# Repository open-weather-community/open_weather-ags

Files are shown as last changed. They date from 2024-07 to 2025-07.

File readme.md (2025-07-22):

# Open-Weather Automated Ground Station (AGS)

An open-source hardware and software project for autonomous weather satellite reception from NOAA satellites using Automatic Picture Transmission (APT). This project enables distributed collection of weather satellite imagery for the open-weather Public Archive.

## Overview

The Open-Weather AGS is designed to be:
- **Autonomous** - Operates without manual intervention
- **Educational** - Entry point for learning about satellites, radio, and weather
- **Resilient** - Graceful handling of failures and network issues
- **Open Source** - All hardware designs, software, and documentation freely available

## Quick Start

If you have a fully assembled AGS:

1. Edit the `ow-config.json` file on the USB drive with your station details
2. Insert the USB drive into your AGS
3. Power on the device
4. The system will automatically start receiving satellite passes

To manually start the application:
```bash
npm start
```

To validate your system setup:
```bash
npm run validate
```

## Configuration

Create (or edit) a file named `ow-config.json` on your USB drive. Here's the configuration template:

```json
{
  "wifiName": "your_wifi_network",
  "wifiPassword": "your_wifi_password",
  "auth_token": "your_openweather_api_token",
  "myID": 1,
  "locLat": 52.49548,
  "locLon": 13.46843,
  "gain": 38,
  "maxDistance": 2200000,
  "daysToPropagate": 1,
  "minElevation": 30,
  "bufferMinutes": 0,
  "numberOfPassesPerDay": 1,
  "sampleRate": "48k",
  "downsample": true,
  "noaaFrequencies": {
    "NOAA 19": "137.1M",
    "NOAA 15": "137.62M"
  },
  "passesFile": "passes.json",
  "saveDir": "/media/openweather/ow",
  "logFile": "log.txt",
  "rtl_fm_path": "/usr/local/bin/rtl_fm",
  "sox_path": "/usr/bin/sox"
}
```

### Essential Configuration Parameters

The following settings are the most important to configure for your station:

- **`myID`** - Unique station identifier (provided by open-weather)
- **`locLat`** / **`locLon`** - Your station's latitude and longitude (decimal degrees)
- **`wifiName`** / **`wifiPassword`** - Your WiFi network credentials
- **`auth_token`** - Your open-weather API authentication token
- **`gain`** - RTL-SDR gain setting (adjust based on signal quality)

### Advanced Configuration

- **`maxDistance`** - Maximum satellite distance in meters to consider a viable pass
- **`daysToPropagate`** - Days in advance to calculate satellite passes
- **`minElevation`** - Minimum pass elevation in degrees (higher = better signal quality)
- **`bufferMinutes`** - Recording buffer time before/after calculated pass times
- **`numberOfPassesPerDay`** - Maximum number of recordings per day

**Note:** NOAA-18 has been removed from the default configuration as it reached end-of-life in 2024 and is no longer operational.

## System Architecture

### Core Components

- **`scheduler.js`** - Main application orchestrator and recording scheduler
- **`config.js`** - Configuration management with backup/recovery system
- **`tle.js`** - Two-Line Element data processing and satellite pass calculation
- **`recorder.js`** - Automated satellite signal recording using RTL-SDR
- **`upload.js`** - Data transmission to open-weather Public Archive
- **`network.js`** - Network connectivity management with ethernet priority
- **`lcd.js`** - LCD display interface for status and error messages
- **`logger.js`** - Centralized logging with file rotation

### File Structure

```
/home/openweather/open_weather-ags/     # Main application directory
├── scheduler.js                        # Main entry point
├── config.js                          # Configuration management
├── *.js                               # Other core modules
└── 3d/                                # 3D printing files
    ├── ready-to-print/
    └── design-and-archive/

/media/[usb-device]/                    # USB storage
├── ow-config.json                      # Station configuration
├── ow-config-backup.json              # Automatic backup
├── passes.json                         # Calculated satellite passes
├── log.txt                            # System logs
└── recordings/                         # Captured audio files
```

## Setup

Regardless of whether or not you use the automatic install vs. a manual install, some things must be prepped on the Raspberry Pi first.

### Raspberry Pi interfaces
+ Install latest [Raspberry Pi OS](https://www.raspberrypi.com/software/). At the time of writing this I am using v12 (Bookworm). It's probably best to stick to this version.
+ Use ```openweather``` for the username.
+ Enable SSH and I2C
```bash
sudo raspi-config
# then Interface, then see SSH and I2C options
```
You can test I2C with:
```bash
sudo i2cdetect -y 1
```
This will give you the address (likely 0x27) which should be used when initializing the device in the node project.

### Create an ssh key for the raspberry pi and add it to github as a deploy key

```sh
ssh-keygen
```

This will grant access to repo pushing rights, so probably not relevant to most (or any) other people.

### Software (quick way -- manual instructions below)

```sh
bash <(curl -s https://gist.githubusercontent.com/prismspecs/17b3a23be1fc6afe79f2788c9797bd21/raw/f21a18a964146081f2a6e9c3b4b80c783bbe24b7/open-weather_installer.sh)
```

```bash
git clone https://github.com/open-weather-community/open_weather-ags.git
cd open_weather-ags
chmod +x install.sh
./install.sh
npm install
```

## Manual Updates

If you need to manually update your AGS to a specific version or development branch, follow these steps:

### 1. Bypass Automatic Version Control

The AGS will automatically download the "regular" version when it boots UNLESS there is a file in your home directory named `bypass-version-check`. Create this file:

```bash
touch ~/bypass-version-check
```

This allows you to continue using the test version straight from GitHub without the system trying to correct itself. To return the AGS to normal automatic updates, simply rename or remove that file.

**Note:** The file does not have an extension (like .txt).

### 2. Remove Current AGS Directory

Remove the existing AGS installation:

```bash
rm -rf ~/open_weather-ags/
```

### 3. Clone the Repository

Clone the desired version from GitHub:

```bash
cd ~
git clone https://github.com/open-weather-community/open_weather-ags.git
```

### 4. Reboot

Restart the system to apply changes:

```bash
reboot
```

After reboot, the system will use your manually installed version instead of automatically updating.

### crontab rebooting

Using sudo, schedule a reboot every morning for 3am
```bash
sudo crontab -e
0 3 * * * /sbin/shutdown -r now
```

### set time to UTC and enable NTP
```sh
timedatectl set-ntp true
timedatectl set-timezone "UTC"
```

### Policy for user to do networking

Since the app needs to connect to wifi networks based on the config file, we need to give the user the necessary permissions to do so.

```sh
sudo nano /etc/polkit-1/localauthority/50-local.d/x.pkla
```

```
[Allow specific user to modify network settings]
Identity=unix-user:openweather
Action=org.freedesktop.NetworkManager.settings.modify.system
ResultAny=yes
```

```sh
sudo systemctl restart polkit
```

NOTE: I don't think this one is actually important, try to skip it
```sh
sudo nano /etc/polkit-1/rules.d/80-network-manager.rules
```

```
polkit.addRule(function(action, subject) {
    if (action.id.indexOf("org.freedesktop.NetworkManager.") === 0 &&
        subject.user == "openweather") {
        return polkit.Result.YES;
    }
});
```

```sh
sudo systemctl restart NetworkManager
```

### USB Drive

Make sure to format whatever USB drive you use as a FAT (or FAT32) drive. The application should automatically detect whatever drive you plug in, so adjusting the mount point, etc. below is optional. These instructions may also be out of date, and I have bricked my install by running fstab improperly before, so be careful.

Format to Fat32 (not sure about these instructions)
```bash
sudo umount /dev/sda1
sudo mkfs.vfat -F 32 -n 'o-w' /dev/sda
sudo chown -R openweather:openweather /media/o-w/
```

```bash
lsblk # identify disk
sudo mkdir /mnt/o-w
sudo nano /etc/fstab
```
Add to fstab:
```
/dev/sda1  /mnt/o-w  vfat  defaults,uid=1000,gid=1000  0  2
```

Reload and mount the drive
```
systemctl daemon-reload
sudo mount -a
```

### Check that it is working
```bash
nvim /home/openweather/cronlog.txt
```

### software (manual way)

#### crontab
This ensures that the node project starts upon reboot.

```
crontab -e
```
```
@reboot /home/openweather/open_weather-ags/start_scheduler.sh
```

#### RTL-SDR v4 driver

+ According to the [official quick start guide](https://www.rtl-sdr.com/V4/) we must purge existing RTL-SDR drivers and install v4 ones anew. Note we are using rtl-sdr-blog drivers and not standard rtl-sdr which do not work with v4.

Purge:
```bash
sudo apt purge ^librtlsdr
sudo rm -rvf /usr/lib/librtlsdr* /usr/include/rtl-sdr* /usr/local/lib/librtlsdr* /usr/local/include/rtl-sdr* /usr/local/include/rtl_* /usr/local/bin/rtl_* 
```
Install:
```bash
sudo apt-get install libusb-1.0-0-dev git cmake pkg-config
git clone https://github.com/rtlsdrblog/rtl-sdr-blog
cd rtl-sdr-blog
mkdir build
cd build
cmake ../ -DINSTALL_UDEV_RULES=ON
make
sudo make install
sudo cp ../rtl-sdr.rules /etc/udev/rules.d/
sudo ldconfig
```

Backlist old drivers(?):
```bash
echo 'blacklist dvb_usb_rtl28xxu' | sudo tee --append /etc/modprobe.d/blacklist-dvb_usb_rtl28xxu.conf
```

Reboot!
```bash
reboot
```

#### SoapySDR

In broad strokes,
First install SWIG so that the Python bindings are created when you build SoapySDR
```bash
sudo apt-get install python-dev-is-python3 swig
```
[First install SoapySDR from GitHub](https://github.com/pothosware/SoapyRTLSDR) [using the wiki instructions](https://github.com/pothosware/SoapyRTLSDR/wiki)
```
git clone https://github.com/pothosware/SoapyRTLSDR.git
cd SoapyRTLSDR
mkdir build
cd build
cmake ..
make
sudo make install
```

Once SoapySDR is installed, test FM recording
```bash
sudo apt install sox
rtl_fm -f 104.6M -M fm -s 170k -r 32k -A fast -l 0 -E deemp -g 10 | sox -t raw -e signed -c 1 -b 16 -r 32000 - fm104-6.wav # FM radio station in Berlin
```

#### Node, nvm and NPM

```bash
sudo apt install -y build-essential libssl-dev
curl -o- https://raw.githubusercontent.com/nvm-sh/nvm/v0.39.1/install.sh | bash
export NVM_DIR="$HOME/.nvm"
[ -s "$NVM_DIR/nvm.sh" ] && \. "$NVM_DIR/nvm.sh"  
[ -s "$NVM_DIR/bash_completion" ] && \. "$NVM_DIR/bash_completion"
nvm install 16.13.2
nvm use 16.13.2
```

Then install ...
```bash
npm install chokidar usb-detection
sudo apt update
sudo apt install libudev-dev
```

#### Raspberry Pi misc setup

##### Nvim
```
sudo apt update
sudo apt install neovim curl
curl -fLo ~/.local/share/nvim/site/autoload/plug.vim --create-dirs \
    https://raw.githubusercontent.com/junegunn/vim-plug/master/plug.vim
mkdir -p ~/.config/nvim
nano ~/.config/nvim/init.vim
```

init.vm:
```
" Specify a directory for plugins
call plug#begin('~/.local/share/nvim/plugged')

" Add plugins here
Plug 'morhetz/gruvbox' " Gruvbox theme
Plug 'junegunn/fzf', { 'do': { -> fzf#install() } } " Fuzzy finder
Plug 'junegunn/fzf.vim' " FZF Vim integration
Plug 'tpope/vim-sensible' " Basic sensible settings

Plug 'neoclide/coc.nvim', {'branch': 'release'}
Plug 'preservim/nerdtree'
Plug 'vim-airline/vim-airline'
Plug 'vim-airline/vim-airline-themes'
Plug 'sheerun/vim-polyglot'
Plug 'sbdchd/neoformat'

" Initialize plugin system
call plug#end()

let g:neoformat_enabled_javascript = ['prettier']

" Enable Gruvbox theme
syntax enable
set background=dark
colorscheme gruvbox

" Basic settings
set number " Show line numbers
set relativenumber " Show relative line numbers
set tabstop=4 " Number of spaces that a <Tab> in the file counts for
set shiftwidth=4 " Number of spaces to use for each step of (auto)indent
set expandtab " Use spaces instead of tabs
set smartindent " Smart auto-indenting
set clipboard=unnamedplus " Use the system clipboard
set mouse=a " Enable mouse support

" Key binding to toggle NERDTree
map <C-n> :Ntree<CR>
```

## helpful links etc
+ [10-day predictions for NOAA-19](https://www.n2yo.com/passes/?s=33591#)
+ [10-day predictions for NOAA-15](https://www.n2yo.com/passes/?s=25338)
+ ~~[10-day predictions for NOAA-18](https://www.n2yo.com/passes/?s=28654&a=1)~~ *(NOAA-18 end-of-life)*
+ [open-weather DIY satellite ground station: workshop resource](https://docs.google.com/document/d/19wAhLYBdl_qCb4kBRlUFztdgenivi1wQb9GiZbTc7fY/edit)
+ [SDR++ manual](https://www.sdrpp.org/manual.pdf)

## Network Management

The AGS includes comprehensive network management that prioritizes ethernet connections over WiFi and displays connection status on the LCD.

### Features

- **Automatic Interface Detection**: Detects ethernet (eth0, enp*, enx*) and WiFi (wlan0, wlp*) interfaces across different Linux distributions
- **Connection Priority**: Ethernet (highest priority) → WiFi (fallback) → Automatic failover
- **LCD Status Display**: Shows connection type and full IP address, updates every 5 minutes
- **Internet Connectivity Verification**: Tests actual internet access using ping to Google DNS (8.8.8.8)

### Network Status Messages

**LCD Display Messages:**
- `ETHERNET ACTIVE` / `IP: 192.168.1.100` - Ethernet connected with internet
- `WIFI ACTIVE` / `IP: 192.168.1.101` - WiFi connected with internet  
- `ETHERNET: Local only` - Ethernet connected but no internet
- `WIFI: Local only` - WiFi connected but no internet
- `NO NETWORK` / `CHECK CABLES` - No active connections

### Configuration

**WiFi Configuration** (in `ow-config.json`):
```json
{
  "wifiName": "YourNetworkName",
  "wifiPassword": "YourPassword"
}
```

**Ethernet Configuration**: Uses DHCP by default, no configuration needed. The system automatically detects interfaces and sets routing priority.

### Network Monitoring

The system automatically:
1. Checks ethernet connection first (highest priority)
2. Falls back to WiFi if ethernet unavailable
3. Displays status on LCD with full IP address
4. Monitors connections every 5 minutes
5. Handles connection failures gracefully

### Troubleshooting Network Issues

**Common Network Commands:**
```bash
# Check interface status
ip link show                    # Show all interfaces
ip addr show                    # Show IP addresses
ip route show                   # Show routing table

# Test connectivity
ping -c 3 8.8.8.8              # Test internet connectivity
ping -c 3 192.168.1.1          # Test local gateway

# NetworkManager commands
nmcli device status             # Show device status
nmcli connection show           # Show connections
nmcli device wifi list          # Show available WiFi networks
```

**Interface Detection Issues:**
- Network interface names vary between systems (eth0, enp*, wlan0, wlp*)
- The system auto-detects interfaces, but you can check available interfaces with `ip link show`
- If ethernet isn't taking priority, NetworkManager may override routing (system attempts automatic priority setting)

**WiFi Connection Problems:**
1. Verify WiFi credentials in config file
2. Check WiFi signal strength
3. Ensure network is broadcasting SSID
4. Check for "No internet despite connection" - system distinguishes between local and internet connectivity

## Troubleshooting

### System Validation

First, run the system validation script to check for common setup issues:

```bash
npm run validate
```

This checks for:
- Node.js version compatibility
- Required system dependencies (rtl-sdr, sox, git)
- Hardware interfaces (I2C for LCD)
- File structure integrity
- Network tools availability

### USB/WiFi Stability Tool

Run the built-in USB stability tool to check for interference issues:

```bash
npm run usb-stability check
```

This checks for:
- USB device enumeration and interference detection
- WiFi connection stability during USB operations
- Power optimization recommendations
- Hardware compatibility issues

### Common Issues & Solutions

#### "Updating Passes" Freeze

**Symptoms:** LCD displays "updating passes" and system becomes unresponsive

**Solutions:**
1. Restart the system - improved timeout handling should prevent freeze
2. Run diagnostic tool to verify DNS and network connectivity
3. Check logs for specific error messages (EAI_AGAIN, ENOTFOUND, timeout)
4. System should automatically use cached TLE data if network fails

#### DNS Resolution Failures

**Symptoms:** "EAI_AGAIN celestrak.org" or "ENOTFOUND" errors in logs

**Solutions:**
1. Check DNS resolution with `nslookup celestrak.org`
2. Verify WiFi credentials and network settings in config
3. Restart network: `sudo systemctl restart NetworkManager`
4. Check USB/WiFi interference with `npm run usb-stability check`

#### Common Startup Issues

**Symptoms:** "Config missing!" or "config error" on LCD

**Solutions:**
1. Check for backup config file (`ow-config-backup.json`) on USB drive
2. System automatically attempts restoration from backup
3. Verify USB drive is properly inserted and mounted
4. Ensure `ow-config.json` contains valid JSON syntax

#### USB/WiFi Interference

**Symptoms:** WiFi disconnections when USB drive is inserted, poor signal quality

**Solutions:**
1. Run interference test: `npm run usb-stability check`
2. Use powered USB hub to reduce Pi power load
3. Use USB 3.0 devices instead of USB 2.0 (different frequency band)
4. Physically separate USB devices from WiFi antenna
5. Use shielded USB cables
6. Switch to 5GHz WiFi networks to avoid 2.4GHz interference

## Development

### Code Structure

The codebase follows a modular architecture with clear separation of concerns:

- **Core modules** (`scheduler.js`, `config.js`, etc.) - Main application logic
- **Hardware interfaces** (`lcd.js`, `recorder.js`) - Hardware abstraction
- **Network services** (`network.js`, `upload.js`) - Network operations  
- **Utilities** (`utils.js`, `constants.js`) - Shared functionality
- **Diagnostics** (`usb-stability.js`) - System health monitoring

### Configuration Management

The system implements robust configuration handling:
- **Atomic writes** - Prevents corruption during power loss
- **Automatic backups** - Creates backup copies for recovery
- **Validation** - Ensures configuration integrity
- **Multi-location search** - Finds configs across mount points

### Error Handling

Comprehensive error handling includes:
- **Network error detection** - Graceful fallback to cached data
- **Timeout protection** - Prevents hanging operations
- **Automatic recovery** - Self-healing from common failures
- **User feedback** - Clear error messages on LCD display

## Contributing

We welcome contributions! Please:

1. **Fork the repository** and create a feature branch
2. **Follow the existing code style** and add JSDoc documentation
3. **Test on actual hardware** - Pi development environment preferred
4. **Update documentation** for any user-facing changes
5. **Submit a pull request** with clear description of changes

### Development Environment

This project is designed for cross-platform development:
- **Development machine** - For coding and version control
- **Raspberry Pi target** - For testing hardware-specific features
- **Remote deployment** - Git-based synchronization workflow

### Code Quality

- Use **JSDoc** for function documentation
- Follow **modular design** principles
- Implement **proper error handling**
- Add **logging** for debugging and monitoring
- **Validate inputs** to prevent runtime errors

## License

ISC License - See repository for details.

## Support

- **GitHub Issues** - Bug reports and feature requests
- **Documentation** - See `plan.md` for detailed technical information
- **Community** - Join the open-weather community discussions
3. Create new `ow-config.json` file on USB drive if no backup available
4. Verify USB drive is properly mounted and accessible

#### USB Drive Issues

**Symptoms:** USB drive detected but config not found

**Solutions:**
1. Ensure USB drive is formatted as FAT32 with label "O-W"
2. Check that `ow-config.json` is in the root directory of the USB drive
3. Try manually mounting: `sudo mount /dev/sda2 /media/openweather/O-W`
4. Check USB drive health and reformat if necessary

### Log File Locations

**Primary Logs:**
- USB Drive: `/media/openweather/O-W/log.txt` (when writable)
- Fallback: `/home/openweather/logs/log.txt` (when USB read-only)
- System Log: `/home/openweather/cronlog.txt` (startup and system events)

**Checking Logs:**
```bash
# System startup logs
tail -f /home/openweather/cronlog.txt

# Application logs (check both locations)
tail -f /home/openweather/logs/log.txt
tail -f /media/openweather/O-W/log.txt
```

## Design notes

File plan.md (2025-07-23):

# Open-weather Automatic Ground Station (AGS) - Project Plan

## Project Overview

The Open-weather Automatic Ground Station (AGS) is an open-source hardware and software project that automatically receives weather satellite imagery from NOAA satellites (NOAA-15, NOAA-19) using Automatic Picture Transmission (APT). This project enables distributed, autonomous collection of weather data for the open-weather Public Archive.

**Note:** NOAA-18 has been removed from the default configuration as it reached end-of-life in 2024 and is no longer operational.

## Project Goals

### Primary Objectives

- Create easy-to-assemble, intuitive ground stations for weather satellite reception
- Enable distributed, automated collection of weather satellite imagery
- Provide educational entry point into radio, satellites, weather, and microcontrollers
- Contribute to open science and climate data accessibility
- Build resilient network of ground stations globally

### Design Philosophy

- **"More is less" approach** - Simplicity in operation and maintenance
- **Local computation** - Calculate satellite orbits on-device rather than relying on third-party services
- **Educational accessibility** - Serve as entry point for learning about radio, satellites, and coding
- **Open source everything** - Hardware designs, software, and documentation freely available
- **Resilient operation** - Graceful handling of failures and network issues

## Technical Architecture

### Hardware Components

- **Raspberry Pi 4** - Main computing platform
- **RTL-SDR dongle** - Software Defined Radio for satellite reception
- **LCD display (I2C)** - Status information and error messages
- **USB storage** - Configuration and data storage
- **Custom 3D-printed case** - Weather protection and mounting
- **External antenna** - V-dipole or other for satellite reception

### Software Stack

- **Runtime:** Node.js (JavaScript/ES modules)
- **Operating System:** Raspberry Pi OS (Bookworm v12)
- **Main Dependencies:**
  - `satellite.js` - Satellite orbit calculations
  - `axios` - HTTP client for API communication
  - `node-cron` - Scheduling system
  - `raspberrypi-liquid-crystal` - LCD display control
  - `geolib` - Geographic calculations
  - `luxon` - Date/time handling

### Development Environment

### Cross-Platform Development Considerations

This project is developed on a separate computer than it is intended to run on. The target deployment platform is a **Raspberry Pi**, which creates several important development considerations:

- **Hardware Dependencies:** The development machine does not have the physical hardware components that the AGS requires:

  - No LCD module connected (I2C display at address 0x27)
  - No RTL-SDR dongle for satellite reception
  - No GPIO pins for hardware interfaces
  - Different CPU architecture (likely x86/x64 vs ARM)

- **Testing Limitations:** Direct testing on the development machine is not practical since:

  - LCD display functions will fail without the actual I2C hardware
  - RTL-SDR recording functions cannot be tested without the radio hardware
  - Satellite pass calculations work but recording simulation is not possible
  - GPIO-dependent features cannot be validated

- **Development Strategy:**

  - **Modular Design:** Code is structured to allow individual module testing where possible
  - **Hardware Abstraction:** Functions that depend on Pi-specific hardware are isolated
  - **Configuration Validation:** Config loading and validation can be tested independently
  - **Logic Testing:** Satellite calculations, scheduling, and data processing can be verified
  - **Remote Deployment:** Code is deployed to actual Raspberry Pi hardware for integration testing

- **Deployment Workflow:**
  - Development and coding done on development machine
  - Version control (git) used for code synchronization
  - Testing deployment to actual Raspberry Pi for hardware validation
  - Remote debugging and logging for troubleshooting hardware-specific issues

This cross-platform development approach requires careful consideration of hardware dependencies and thorough testing on the target Raspberry Pi platform before considering any release ready for production use.

## Core Modules

#### 1. Scheduler (`scheduler.js`)

- **Purpose:** Main application orchestrator
- **Functions:**
  - System initialization and configuration loading
  - WiFi connectivity verification
  - Satellite pass scheduling and execution
  - Recording session management
  - Reboot overlap detection (2:50-3:10 AM buffer)

#### 2. Configuration System (`config.js`)

- **Purpose:** Dynamic configuration management with backup recovery
- **Functions:**
  - USB-based config file discovery
  - Runtime configuration loading/saving
  - Multi-mount point searching (`/media`, `/mnt`)
  - Automatic backup config creation and restoration
  - Config validation and error recovery

#### 3. Satellite Pass Prediction (`passes.js`, `tle.js`)

- **Purpose:** Calculate and manage satellite passes
- **Functions:**
  - Download Two-Line Element (TLE) data
  - Calculate satellite passes for configured location
  - Filter passes by elevation, distance, and timing
  - Select optimal passes for recording

#### 4. Recording System (`recorder.js`)

- **Purpose:** Automated satellite signal recording
- **Functions:**
  - RTL-SDR control via `rtl_fm`
  - Audio processing with SoX (downsampling, format conversion)
  - File management and timestamping
  - Signal quality optimization

#### 5. Upload System (`upload.js`)

- **Purpose:** Data transmission to public archive
- **Functions:**
  - Retry logic for failed uploads
  - Metadata packaging (location, timestamp, satellite info)
  - Progress monitoring and logging

#### 6. Display Interface (`lcd.js`)

- **Purpose:** User feedback and status display
- **Functions:**
  - Real-time status updates
  - Error message display
  - Scrolling text (marquee) for long messages
  - Next recording time display

#### 7. System Management (`disk.js`, `wifi.js`, `logger.js`)

- **Purpose:** System health and maintenance
- **Functions:**
  - Disk space monitoring and cleanup
  - WiFi connectivity management
  - Comprehensive logging with rotation

## Configuration Schema

The AGS uses a JSON configuration file (`ow-config.json`) stored on USB storage. The system automatically creates a backup file (`ow-config-backup.json`) to protect against config file corruption or disappearance:

```json
{
  "myID": 1, // Unique station identifier
  "locLat": 52.49548, // Latitude (decimal degrees)
  "locLon": 13.46843, // Longitude (decimal degrees)
  "gain": 38, // RTL-SDR gain setting
  "maxDistance": 2200000, // Maximum satellite distance (meters)
  "daysToPropagate": 1, // Days ahead to calculate passes
  "minElevation": 30, // Minimum pass elevation (degrees)
  "bufferMinutes": 0, // Recording buffer time
  "numberOfPassesPerDay": 1, // Max recordings per day
  "sampleRate": "48k", // Recording sample rate
  "downsample": true, // Enable audio downsampling
  "noaaFrequencies": {
    // Satellite frequencies
    "NOAA 19": "137.1M",
    "NOAA 15": "137.62M"
  },
  "wifiName": "network_name",
  "wifiPassword": "password",
  "auth_token": "api_token",
  "passesFile": "passes.json",
  "logFile": "log.txt",
  "rtl_fm_path": "/usr/local/bin/rtl_fm",
  "sox_path": "/usr/bin/sox"
}
```

## Data Flow Architecture

1. **Initialization**

   - Load configuration from USB storage
   - Initialize LCD display and logging
   - Verify WiFi connectivity

2. **Pass Calculation**

   - Download TLE data for NOAA satellites
   - Calculate passes for current location
   - Filter by elevation, distance, and timing constraints
   - Select best passes for recording

3. **Recording Pipeline**

   - Schedule recordings using precise timing
   - Execute RTL-SDR capture at correct frequency
   - Process audio (demodulation, filtering, downsampling)
   - Save to local storage with metadata

4. **Upload Process**

   - Package recording with metadata (location, time, satellite)
   - Upload to open-weather Public Archive API
   - Implement retry logic for network failures
   - Clean up local files after successful upload

5. **System Maintenance**
   - Monitor disk space and cleanup old recordings
   - Rotate log files to prevent storage overflow
   - Daily reboot at 3:00 AM for system refresh
   - Automatic software updates

## Technical Specifications

### Minimum Hardware Requirements

- **Raspberry Pi 4** (2GB+ RAM recommended)
- **RTL-SDR v3 dongle** or compatible
- **16GB+ USB storage** (FAT32 formatted)
- **LCD display** (16x2, I2C interface at 0x27)
- **Antenna** (V-dipole or Yagi, tuned for 137MHz)

### Software Dependencies

- **Raspberry Pi OS** Bookworm (v12)
- **RTL-SDR tools** (`rtl_fm`)
- **SoX audio processing**
- **Node.js** (latest LTS)
- **I2C tools** for LCD communication

### Network Requirements

- **WiFi connectivity** for uploads
- **Open-weather API access** with authentication token
- **NTP synchronization** for accurate timing

### Performance Characteristics

- **Recording frequency:** 137.1-137.9 MHz
- **Sample rate:** 48 kHz (downsampled to 11.025 kHz)
- **Recording duration:** 10-15 minutes per pass
- **Upload size:** ~2-5 MB per recording
- **Power consumption:** ~5W average, ~8W during recording

## File System Structure

```
/home/openweather/open_weather-ags/
├── scheduler.js          # Main application entry point
├── config.js            # Configuration management
├── passes.js            # Satellite pass calculations
├── tle.js              # TLE data processing
├── recorder.js         # Recording system
├── upload.js           # Upload functionality
├── lcd.js              # LCD display control
├── disk.js             # Disk management
├── wifi.js             # Network connectivity
├── logger.js           # Logging system
├── package.json        # Node.js dependencies
├── install.sh          # Installation script
├── start_scheduler.sh  # Startup script
└── 3d/                 # 3D printing files
    ├── ready-to-print/
    └── design-and-archive/

/media/[usb-device]/
├── ow-config.json      # Station configuration
├── ow-config-backup.json # Automatic backup of configuration
├── passes.json         # Calculated satellite passes
├── log.txt            # System logs
└── recordings/        # Captured audio files
```

## System Integration

### Cron Jobs

```bash
# Daily reboot for system refresh
0 3 * * * /sbin/shutdown -r now

# Automatic startup
@reboot /home/openweather/open_weather-ags/start_scheduler.sh
```

### System Services

- **NetworkManager** - WiFi configuration management
- **NTP** - Time synchronization (UTC)
- **I2C** - Hardware communication for LCD

### Security Considerations

- User permissions for network configuration
- Secure API token storage
- Local file system access controls
- Regular security updates via installation script

## Testing & Quality Assurance

### Configuration Backup & Recovery System

**Issue Addressed:** Documented cases of the `ow-config.json` file spontaneously disappearing or becoming corrupted on the AGS USB drive, even after successful operation for multiple days.

**Root Causes Identified:**

- **Power Interruptions:** Daily 3 AM reboots and power outages during file writes
- **FAT32 Vulnerabilities:** No journaling, cached writes, cheap USB drive firmware
- **Unnecessary Writes:** Config file was rewritten on every startup, creating corruption opportunities
- **Non-atomic Operations:** Simple file writes vulnerable to power loss mid-operation

**Solution Implemented:**

- **Automatic Backup Creation:** Every time the primary config is successfully loaded, a backup file (`ow-config-backup.json`) is created with timestamp metadata
- **Atomic File Operations:** All config writes use atomic write-to-temp-then-rename operations to prevent corruption
- **Smart Write Detection:** Config files are only rewritten when changes are actually needed
- **Validation:** All config files are validated for required fields before use
- **Recovery Mechanism:** If the primary config is missing or corrupted, the system automatically restores from the backup
- **Multi-location Search:** System searches all USB mount points for backup configs if primary is completely missing
- **User Feedback:** LCD displays specific error messages to help users understand config issues

**Files Created:**

- `ow-config-backup.json` - Automatic backup with timestamp metadata
- `configPath.json` - Tracks the last known config location

**Recovery Process:**

1. Attempt to load primary config (`ow-config.json`)
2. If corrupted, try to restore from backup in same directory
3. If primary missing entirely, search all USB devices for any backup config
4. Restore backup to primary config location
5. Continue normal operation

### Known Issues & Current Limitations

- **Reboot scheduling:** System reboots at 3:00 AM may conflict with long satellite passes
- **USB/WiFi interference:** Some hardware configurations experience WiFi issues when USB storage is connected
- **Network resilience:** Limited offline operation capabilities (improved with TLE caching)
- **Antenna optimization:** Performance varies significantly with antenna setup

### Troubleshooting & Diagnostics

The system includes comprehensive diagnostic tools:

**Available Diagnostic Commands:**
```bash
npm run usb-stability     # USB/WiFi interference testing and power optimization
```

**Key Diagnostic Features:**
- DNS resolution and network connectivity testing
- USB device enumeration and interference detection
- WiFi scanning and connection verification
- TLE cache validation and Celestrak connectivity
- System resource monitoring
- **WiFi connection preservation** - Avoids unnecessary disconnections on startup
- **Existing connection validation** - Verifies working connections before reconnecting

**Enhanced WiFi Management:**
- **Smart Connection Handling:** System now preserves existing WiFi connections if they're working properly
- **Reduced Startup Disruption:** No longer disconnects from working WiFi during boot process
- **Connection Verification:** Validates internet connectivity before deciding to reconnect
- **Detailed WiFi Diagnostics:** New test-wifi command provides comprehensive WiFi troubleshooting

**Enhanced WiFi Debugging:**
- Detailed network discovery logging showing all available networks
- USB device detection during WiFi operations
- Specific error classification (network not found vs authentication failed)
- Hardware status checking (rfkill, interface state)
- Connection verification with IP assignment and internet testing

**Smart Network Priority Management:**
- Network priority is only set when both ethernet and WiFi are active and ethernet has internet
- WiFi maintains default priority when it's the only working connection
- Prevents unnecessary lowering of WiFi priority when ethernet is unavailable
- Improved connection stability when operating with WiFi-only connectivity

**Common USB/WiFi Interference Solutions:**
1. Use powered USB hub to reduce Pi power load
2. Use USB 3.0 devices instead of USB 2.0 (different frequency)
3. Physically separate USB devices from WiFi antenna
4. Use shielded USB cables
5. Use 5GHz WiFi networks to avoid 2.4GHz interference

**System Recovery Features:**
- Automatic configuration backup and restoration
- TLE data caching with 7-day fallback
- Intelligent error recovery with automatic restart
- Timeout protection on all network operations
- Graceful degradation when network services fail

## Recent Improvements (July 2025)

**Network Status Detection Fix:**
- Fixed critical bug in `getNetworkStatusQuiet()` function that was incorrectly calling `checkWifiConnection()` without required parameters
- Improved network status detection to properly identify existing WiFi connections during system startup
- Fixed inconsistency where network initialization would fail but WiFi was actually working
- Enhanced status reporting to include proper `primary` and `ip` fields for consistent status display

**Network Priority Management Fix:**
- Fixed network priority logic to only set WiFi as lower priority when ethernet is actually available and working
- Prevents WiFi from being unnecessarily deprioritized when ethernet is down or unavailable
- Maintains optimal connectivity when WiFi is the primary/only connection
- Improved logging to clearly indicate when and why priority changes are made

## Previous Improvements (December 2024)

**WiFi Connection Management:**
- Enhanced connection preservation logic to avoid unnecessary disconnections
- Improved startup behavior to verify existing connections before reconnecting
- Added comprehensive WiFi diagnostic tool (`test-wifi-connection.js`)
- Reduced aggressive network interface resets that caused stability issues

**Logging System:**
- Increased log retention by 50% (from 1000 to 1500 lines)
- Extended deletion threshold to preserve more debugging information
- Maintained rotation efficiency while providing longer troubleshooting history

This system is designed for resilient, autonomous operation with comprehensive error handling and diagnostic capabilities.

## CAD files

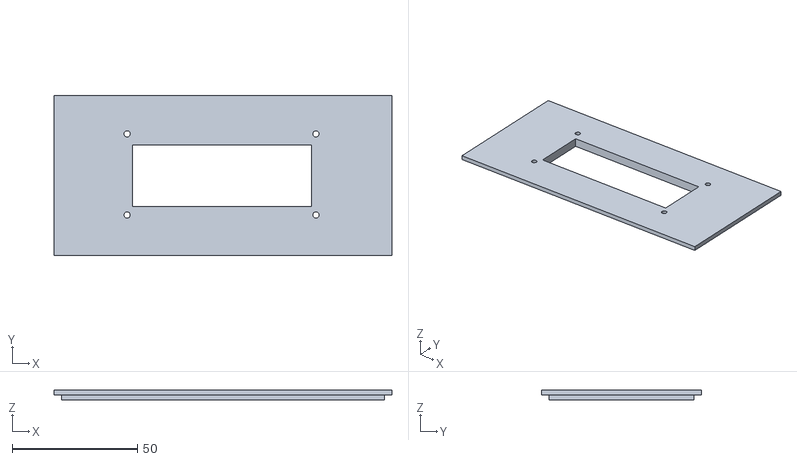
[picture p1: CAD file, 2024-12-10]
3d/case-lid-notext.stl
135.0 x 64.0 x 4.00

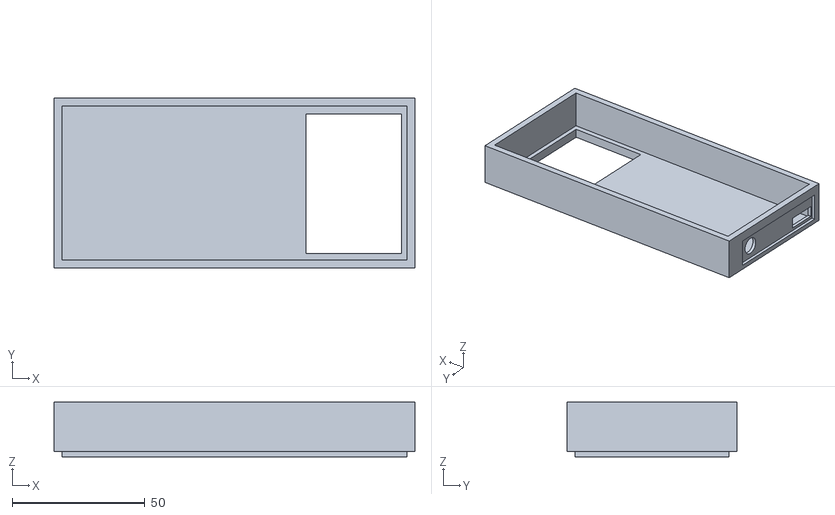
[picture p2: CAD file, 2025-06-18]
3d/ready-to-print/case-middle-bottom.stl
136.0 x 64.0 x 20.6

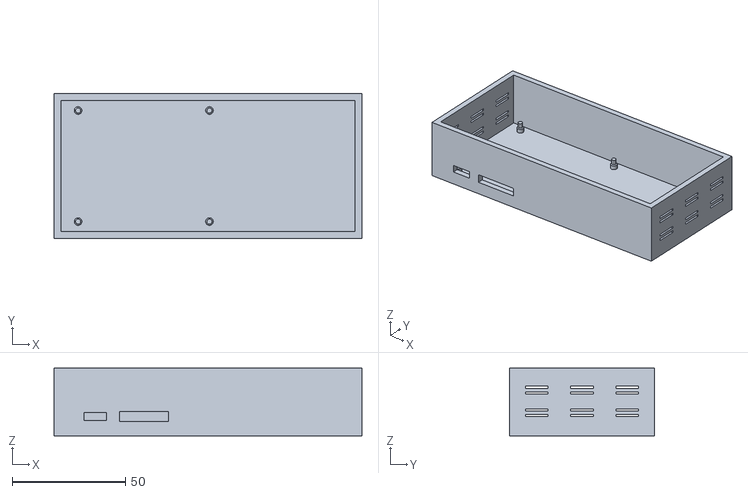
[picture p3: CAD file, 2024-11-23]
3d/case-base.stl
136.0 x 64.0 x 30.0

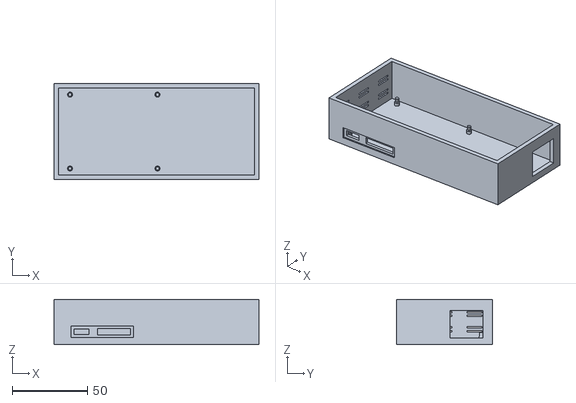
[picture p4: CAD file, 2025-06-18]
3d/ready-to-print/case-base.stl
136.0 x 64.0 x 30.0

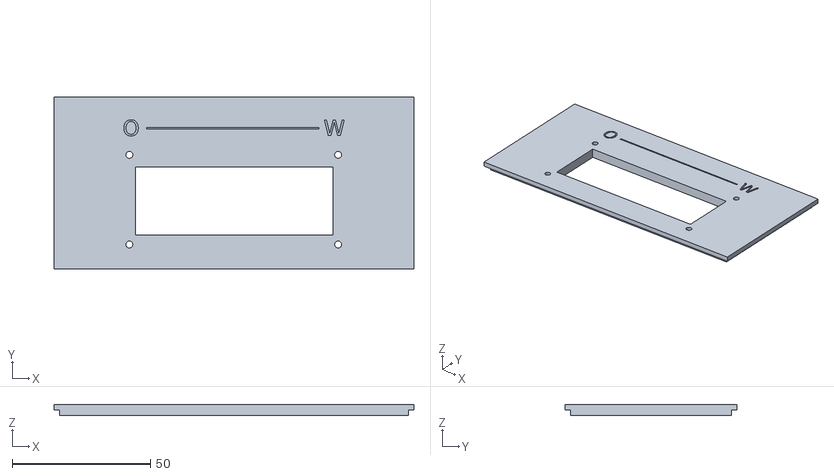
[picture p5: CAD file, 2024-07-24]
3d/case-lid5.stl
130.0 x 62.0 x 4.00

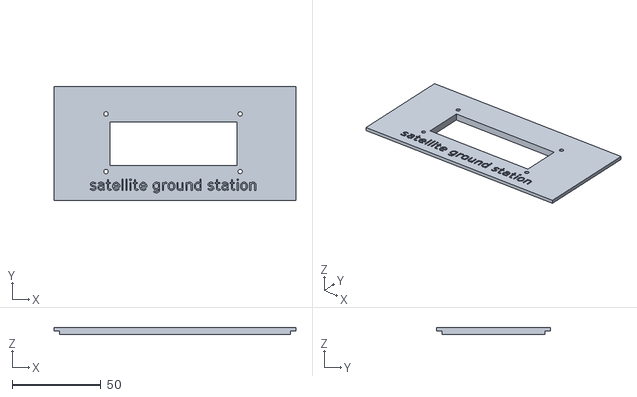
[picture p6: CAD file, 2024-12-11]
3d/ready-to-print/case-lid.stl
136.0 x 64.0 x 4.00

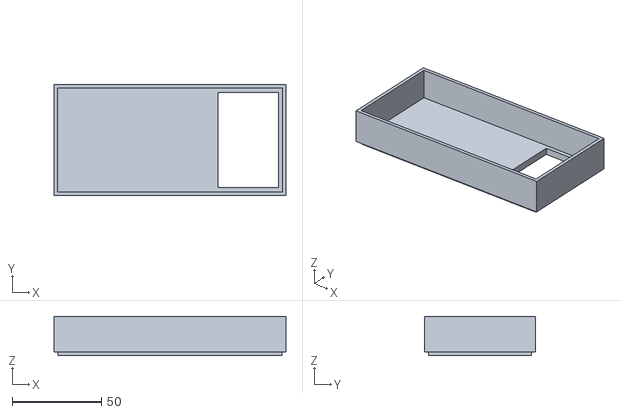
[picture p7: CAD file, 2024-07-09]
3d/case-middle-top5.stl
130.0 x 62.0 x 22.0

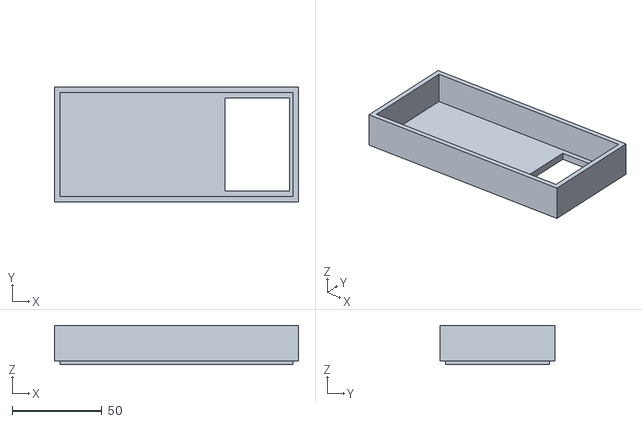
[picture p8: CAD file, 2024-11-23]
3d/ready-to-print/case-middle-top.stl
136.0 x 64.0 x 22.0

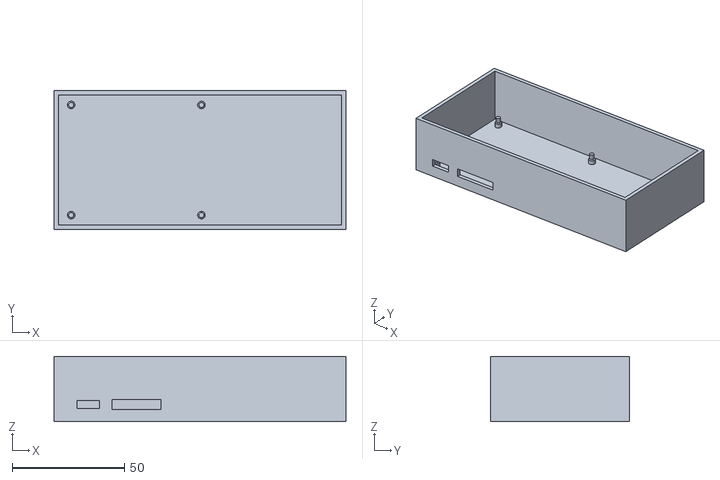
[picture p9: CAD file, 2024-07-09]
3d/case-base5.stl
130.0 x 62.0 x 29.0

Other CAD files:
3d/case-staging.blend
3d/case-staging2.blend
3d/design-and-archive/case-staging.blend
3d/design-and-archive/case-staging2.blend
3d/design-and-archive/lid-staging.blend
3d/lid-staging.blend

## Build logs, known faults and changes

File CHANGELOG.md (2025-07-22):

# Changelog

All notable changes to the Open-Weather AGS project will be documented in this file.

## [Unreleased] - Code Cleanup & Documentation Improvements

### Added
- **JSDoc documentation** - Added comprehensive function documentation across core modules
- **Utility module** (`utils.js`) - Centralized common helper functions
- **Constants module** (`constants.js`) - System-wide configuration constants
- **Enhanced configuration validation** - Better validation with specific error messages
- **Improved README** - Comprehensive documentation with development guidelines

### Improved
- **Error handling** - Consistent error handling patterns across modules
- **Code organization** - Reduced duplication and improved maintainability
- **Validation** - Enhanced config validation with range checking
- **Documentation** - Updated plan.md and README with current system state

### Removed
- **Unnecessary dependencies** - Cleaned up package.json dependencies
- **Deprecated diagnostic scripts** - Removed references to non-existent npm scripts
- **Code duplication** - Moved common functions to utility modules

### Fixed
- **Package.json cleanup** - Removed unnecessary and duplicate dependencies
- **Documentation consistency** - Aligned docs with actual codebase functionality
- **Error message clarity** - More specific validation and error messages

### Technical Improvements
- **Modular architecture** - Better separation of concerns
- **Type safety** - Enhanced validation for configuration parameters
- **Developer experience** - Better documentation and code organization
- **Maintainability** - Reduced technical debt and improved code quality

## [1.4.2b3] - 2025-07-22

### Added
- Comprehensive JSDoc documentation across all modules
- `utils.js` module with centralized utility functions
- `constants.js` module for system-wide configuration constants
- `validate-system.js` script for pre-flight system checks
- Quiet network monitoring with condensed logging

### Fixed
- Configuration validation now accepts `myID: 0` with warning (for placeholder configs)
- Network monitoring reduced from 3 verbose log lines every 10 minutes to 1 condensed line every 30 minutes
- Removed duplicate network status functions
- Enhanced error handling and validation throughout codebase

### Changed
- Updated `package.json` to remove built-in Node.js modules from dependencies
- Network monitoring interval increased from 10 to 30 minutes for reduced log noise
- Improved configuration backup and recovery system
- Enhanced validation with detailed error messages

### Removed
- References to non-existent npm scripts from documentation
- Unnecessary verbose logging during network monitoring
- Redundant dependency declarations

---

### Development Notes

This changelog follows [Keep a Changelog](https://keepachangelog.com/en/1.0.0/) format.

**Version format**: `MAJOR.MINOR.PATCH[PRERELEASE]`
- **MAJOR**: Breaking changes
- **MINOR**: New features, backwards compatible
- **PATCH**: Bug fixes, backwards compatible  
- **PRERELEASE**: Beta versions (e.g., `b1`, `b2`, `rc1`)

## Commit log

2024-07-03 3d models for printing
    [case-base.stl, case-lid.stl, case-middle-bottom.stl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]
2024-07-09 Add files via upload
    updated the case specs:
    + increase wall thickness to 2mm
    + increase click-in dropdown to 2mm
    + increase base height 4mm
    + increase top section height quite a bit
    [case-base3.stl, case-lid3.stl, case-middle-bottom3.stl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]
2024-07-09 updated 3d model
    [case-base2.stl, case-base4.stl, case-lid2.stl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]
2024-07-09 fixed lid
    [case-lid4.stl]
2024-07-24 new 3d printer models
    [case-base5.stl, case-lid5.stl, case-middle-bottom5.stl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]
2024-07-29 fixing readme
    [case-base.stl, case-base2.stl, case-base3.stl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]
2024-08-02 fixed 3d staging file and re-added
    [case-staging.blend]
2024-08-02 small blender adjustments
    [case-staging.blend]
2024-08-05 organized 3d files
    [case-base.stl, case-lid.stl, case-middle-bottom.stl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]
2024-08-05 put ground station ready back
2024-08-10 updated 3d printing design
    [case-base.stl, case-lid.stl, case-middle-bottom.stl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]
2024-08-26 updated 3d models
    [case-base.stl, case-lid.stl, case-middle-bottom.stl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]
2024-10-20 switching startup script
2024-11-06 added local time conversion and message. also attempted fix of downsampler
    [case-lid-notext.stl, case-lid.stl]
2024-11-23 tried a fix for recorder so that it defaults to no downsampling, but sox inserts headers on non downsampled file too
    [case-base.stl, case-lid-notext.stl, case-lid.stl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]
2024-11-27 reset samplerate to 48k
2024-12-10 scheduler can record X per day, recorder.js has new better values, start_scheduler waits 10 more seconds to account for disk mounting, config.js skips hidden folders
    [case-lid-notext.stl, case-lid.stl, lid-staging.blend]
2024-12-11 made startup sleep time 60 seconds
    [case-lid.stl, case-staging2.blend]
2024-12-28 added new clock readout and -F 9 option to recorder
    [case-base-thinpower.stl]
2025-01-12 timezone is now set using tzupdate, all devices run on local time
2025-05-09 reorganized printing stuff
    [case-base-thinpower.stl, case-base.stl, case-lid-notext.stl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]
2025-06-18 updated 3d models and startup script
    [case-base-thinpower.stl, case-base.stl, case-middle-bottom.stl]
2025-06-24 ethernet switching test
2025-07-12 trying to update usb mounting
